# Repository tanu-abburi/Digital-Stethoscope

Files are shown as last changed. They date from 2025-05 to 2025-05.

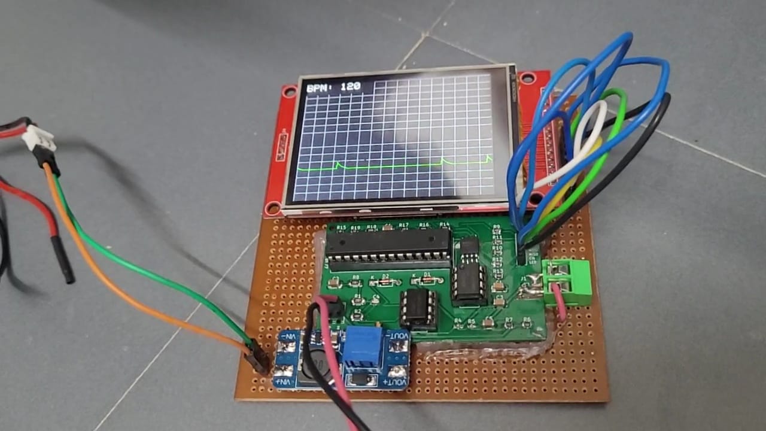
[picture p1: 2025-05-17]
Test setups/hr_120.jpeg

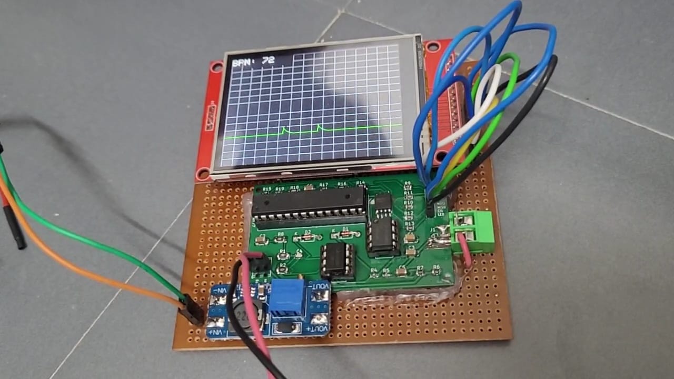
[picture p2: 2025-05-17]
Test setups/hr_72.jpeg

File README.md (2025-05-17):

# Digital Stethoscope  
A **digital stethoscope** that amplifies, filters, and digitally processes heart sounds for enhanced diagnostics and remote monitoring.  
## Project Outline
We intend on developing a digital stethoscope system which includes an acoustic sensor that is attached to the processing unit, which will catch the signal, amplify it using an amplifier circuit using an op amp TL082.
The amplified signal is then sent to the ATMEGA328-P, which then converts the analog signal to a digital one ,which is then displayed as a waveform on the LCD TFT screen.  We intend to 3D printing an enclosure which will offer mechanical support and keep the enclosure compact.
## Working
The custom acoustic sensor is positioned on a pulse point of the body.
The sound is transmitted to an amplifier circuit via a condenser microphone. 
The amplified signal is then sent to the A0 ADC pin of the  ATmega328P microcontroller, where it is processed and displayed on the LCD screen.
On the LCD screen, we display to waveform as well as the calculated BPM rate .

## Simulation Results
WhatsApp Image 2025-05-11 at 23 04 28

## Schematic

## PCB Layout and 3D view



##  Team Members  
- **Ashley Ann Benoy** - EE23BTECH11204  
- **Avani Chouhan** - EE23BTECH11205  
- **Abburi Tanusha** - EE23BTECH11201  
- **Manugunta Meghana Sai** - EE23BTECH11212  
- **Muthyala Nikhitha Sri** - EE23BTECH11213

## System

## References
https://circuitdigest.com/microcontroller-projects/diy-wireless-digital-stethoscope

https://people.ece.cornell.edu/land/courses/ece4760/FinalProjects/s2012/myw9_gdd9/myw9_gdd9/

https://circuitdigest.com/fullimage?i=circuitdiagram_mic/Wireless-Stethoscope-Circuit.png

https://www.youtube.com/watch?v=w6MbM_f_7Uo

https://www.youtube.com/watch?v=QSXJG3opua8&t=3s

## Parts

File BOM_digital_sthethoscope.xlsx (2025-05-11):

S.No | Components' name | Components' Value | Manufacturer name | Package/Footprint | Quantity | Cost per unit | Net cost | Brief Description
1 | Capacitors | 100 n | Robu | Smd 1206 | 10 | 1.54 | 15.4
2 |  | 10 u | Robu | smd 1206 | 20 | 9 | 180
3 |  | 500 p | Mouser Electronics | smd 0805 | 10 | 26 | 260
4 |  | 2.2u | Robu | smd 0805 | 10 | 5 | 50
5 |  | 470n | Robu | smd 1206 | 10 | 4 | 40
6 | Resistors | 10k | Robu | smd 0805 | 25 | 3 | 75
7 |  | 1k | Robu | smd 0805 | 20 | 0.65 | 13
8 |  | 20k | Robu | smd 0603 | 10 | 0.15 | 1.5
9 |  | 2.2k | Robu | smd 0805 | 10 | 0.98 | 9.8
10 |  | 1 Meg | Robu | smd 1206 | 10 | 0.65 | 6.5
11 |  | 100 | Robu | smd 0805 | 20 | 3 | 60
12 |  | 200 | Robu | smd 1206 | 15 | 0.49 | 7.35
13 |  | 3.3k | Robu | smd 1206 | 10 | 0.69 | 6.9
14 |  | 75 | Robu | smd 1206 | 10 | 1 | 10
15 |  | 100k | Robu | smd 1206 | 20 | 0.79 | 15.8
16 | Diode | Zener diode | Digikey | 1N4148: Diode_THT:D_DO-35_S0D27_P7.62MM_Horizontal | 10 | 8.63 | 86.3
17 | flash memory | W25Q80DVSSIG | robu | SOIC-8/SMD | 2 | 79 | 158 | Storing and transferring the data
18 | Stethoscope |  | ELKO |  | 2 | 1661 | 3322 | Detects heartbeats and transmits real-time pulse data for remote monitoring and analysis.
19 | microcontoller ic | ATmega328p | Robu | PDIP-28 | 2 | 340 | 680 | pulse width modulation and ADC unit
20 | voltage regulator |  | Robu | DIP | 3 | 101 | 303 | voltage regulator to output voltage of 3.3V
21 | 28 pin DIP IC Socket |  | Robu |  | 2 | 28 | 56 | Allows easy insertion and removal of 28-pin ICs
22 | Switch |  | Robu |  | 3 | 69 | 207 | Basic on/off switch with two terminals
23 | LCD screen | TFT 2.8 inch LCD screen touch enabled | robu |  | 2 | 746 | 1492 | For plotting the graph
24 | female header pin |  | robu |  | 1 | 127 | 127 | connecting header pins
25 | male header pin |  | robu |  | 1 | 100 | 100 | connecting header pins
26 | Operational amplifier | OA3 TL082 | Robu | DIP-8 | 4 | 132 | 528 | amplification of signal
27 | 1.2V Battery |  | Amazon |  | 2 | 954 | 1908 | Supply DC Power
28 | Microphone |  | MOUSER Electronics |  | 5 | 56 | 280 | Capturing input signal from stethoscope
29 | Battery Holder |  | Amazon |  | 2 | 149 | 298 | To hold the battery
30 | sd card |  | robu |  | 1 | 419 | 419 | additional memory
31 | DC-DC setup power module |  | robu |  | 2 | 36 | 72 | bb
32 | Lithium Battery |  | robu |  | 2 | 209 | 418 | power supply
33 | 9V Battery |  | Amazon |  | 1 | 249 | 249 | Supply DC Power
34 | Terminal Block |  | robu |  | 2 | 8 | 16

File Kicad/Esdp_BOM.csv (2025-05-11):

Reference | Value | Datasheet | Footprint | Qty | DNP
C1,C3 | 100nF | ~ | Capacitor_SMD:C_1206_3216Metric | 2
C2,C5,C6 | 10uF | ~ | Capacitor_SMD:C_1206_3216Metric | 3
C4 | 500pF | ~ | Capacitor_SMD:C_0805_2012Metric | 1
D1,D2 | 1N4148 | https://assets.nexperia.com/documents/data-sheet/1N4148_1N4448.pdf | Diode_THT:D_DO-35_SOD27_P7.62mm_Horizontal | 2
IC1 | W25Q80DVSSIG |  | W25Q80DVSSIG:SOIC8-FLASH | 1
J1 | Conn_01x02_Pin | ~ | Connector_PinSocket_1.27mm:PinSocket_1x02_P1.27mm_Vertical | 1
J2 | Screw_Terminal_01x02 | ~ | TerminalBlock_Phoenix:TerminalBlock_Phoenix_MPT-0,5-2-2.54_1x02_P2.54mm_Horizontal | 1
J3 | Conn_01x09_Pin | ~ | Connector_PinSocket_1.27mm:PinSocket_1x09_P1.27mm_Vertical | 1
R1,R8 | 3.3k | ~ | Resistor_SMD:R_1206_3216Metric | 2
R2 | 1M | ~ | Resistor_SMD:R_1206_3216Metric | 1
R3,R9,R10,R11,R12,R13 | 10k | ~ | Resistor_SMD:R_0805_2012Metric | 6
R4,R5 | 20k | ~ | Resistor_SMD:R_0603_1608Metric | 2
R6,R7 | 1k | ~ | Resistor_SMD:R_0805_2012Metric | 2
R14,R16,R18 | 200 | ~ | Resistor_SMD:R_1206_3216Metric | 3
R15,R17,R19 | 100 | ~ | Resistor_SMD:R_0805_2012Metric | 3
U1 | ATmega328-P | http://ww1.microchip.com/downloads/en/DeviceDoc/ATmega328_P%20AVR%20MCU%20with%20picoPower%20Technology%20Data%20Sheet%2040001984A.pdf | Package_DIP:DIP-28_W7.62mm_Socket | 1
U2 | TL082 | http://www.ti.com/lit/ds/symlink/tl081.pdf | Package_DIP:DIP-8_W7.62mm_LongPads | 1
U3 | LP2951-3.3_DIP | http://www.ti.com/lit/ds/symlink/lp2951.pdf | Package_DIP:DIP-8_W7.62mm | 1

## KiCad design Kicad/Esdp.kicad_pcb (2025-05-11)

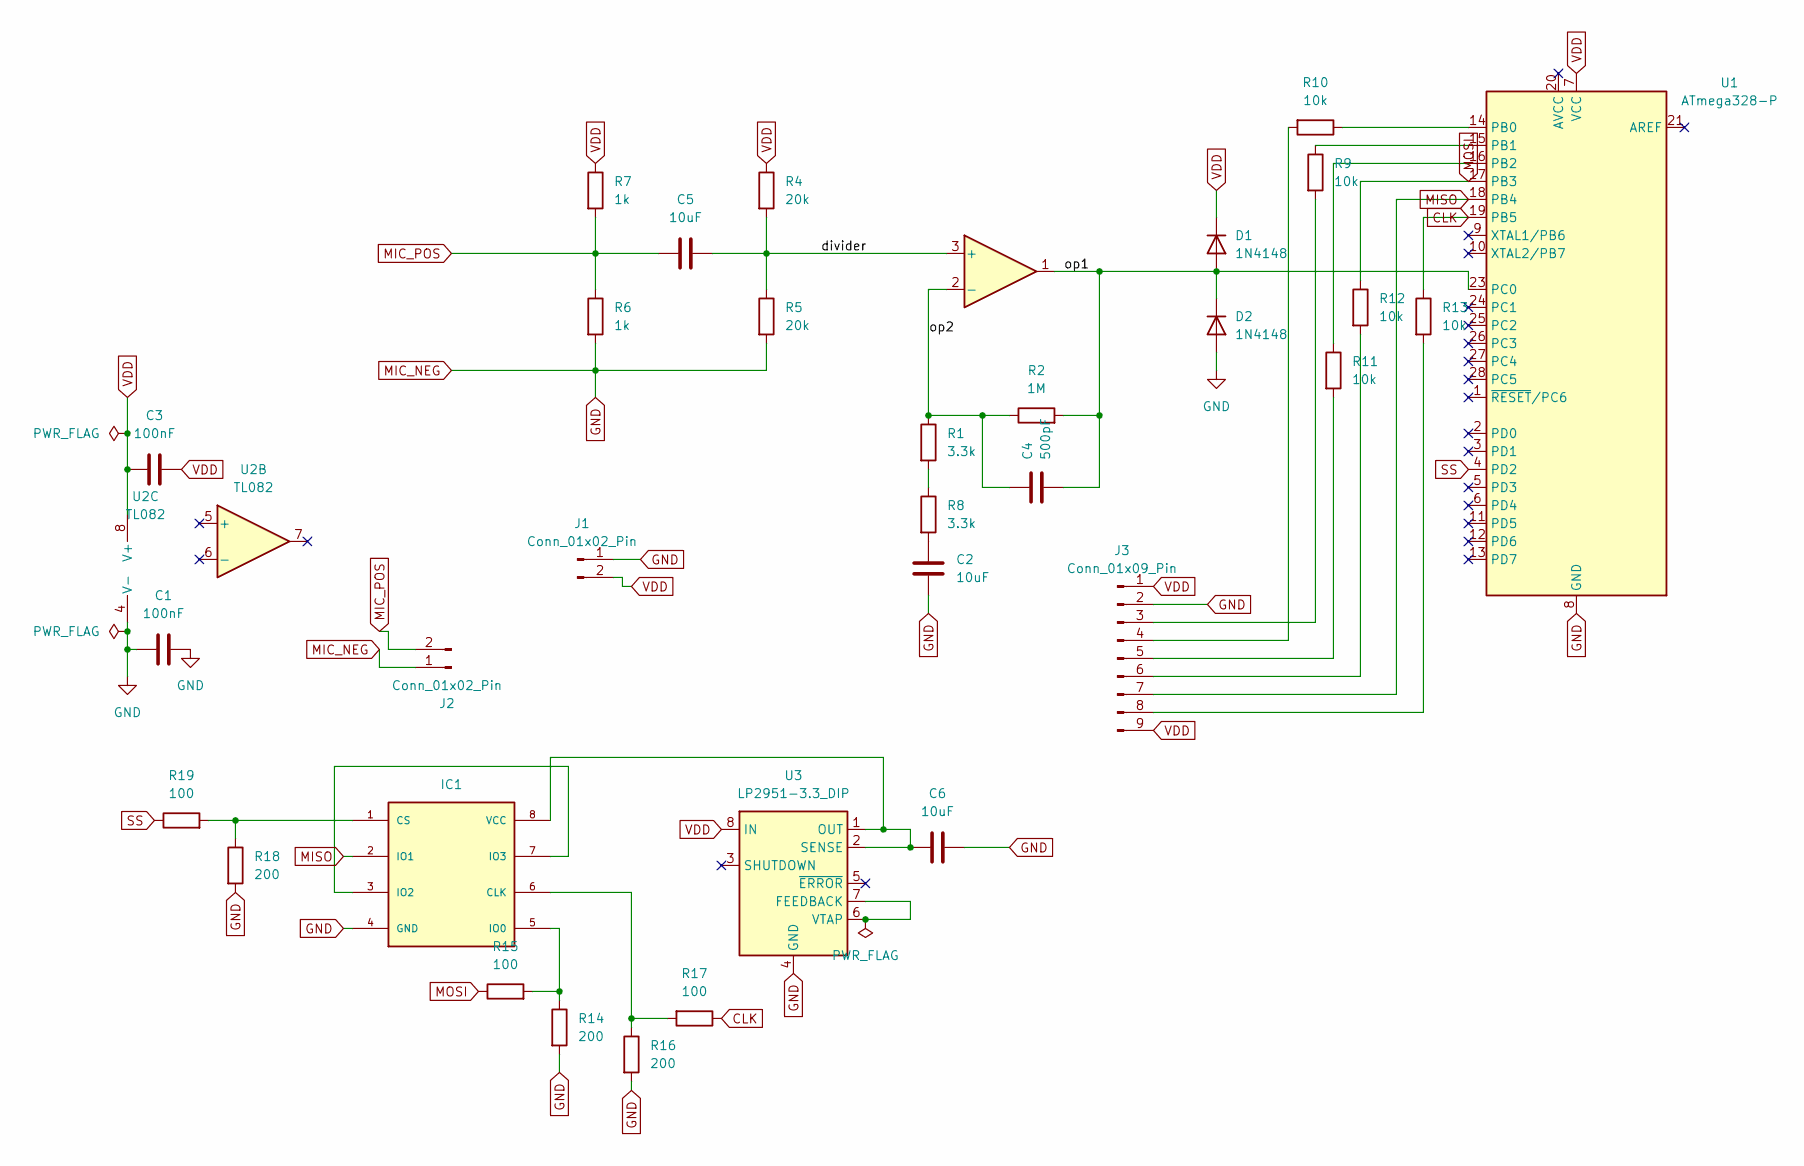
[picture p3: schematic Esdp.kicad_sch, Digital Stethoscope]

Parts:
C1, C3: 100nF; C_1206_3216Metric
C2, C5, C6: 10uF; C_1206_3216Metric
C4: 500pF; C_0805_2012Metric
D1, D2: 1N4148; D_DO-35_SOD27_P7.62mm_Horizontal
IC1: W25Q80DVSSIG; SOIC8-FLASH
J1: Conn_01x02_Pin; PinSocket_1x02_P1.27mm_Vertical
J2: Conn_01x02_Pin; TerminalBlock_Phoenix_MPT-0,5-2-2.54_1x02_P2.54mm_Horizontal
J3: Conn_01x09_Pin; PinSocket_1x09_P1.27mm_Vertical
R1, R8: 3.3k; R_1206_3216Metric
R2: 1M; R_1206_3216Metric
R4, R5: 20k; R_0603_1608Metric
R6, R7: 1k; R_0805_2012Metric
R9, R10, R11, R12, R13: 10k; R_0805_2012Metric
R14, R16, R18: 200; R_1206_3216Metric
R15, R17, R19: 100; R_0805_2012Metric
U1: ATmega328-P; DIP-28_W7.62mm_Socket
U2: TL082; DIP-8_W7.62mm_LongPads
U3: LP2951-3.3_DIP; DIP-8_W7.62mm

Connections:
/divider: C5.1, R4.2, R5.1, U2.3 (+)
/op1: C4.2, D1.2 (A), D2.1 (K), R2.2, U1.23 (PC0), U2.1
/op2: C4.1, R1.1, R2.1, U2.2 (-)
CLK: R13.1, R17.1, U1.19 (PB5)
GND: C1.1, C1.2, C2.2, C6.1, D2.2 (A), IC1.4 (GND), J1.1, J2.1, J3.2, R5.2, R6.2, R14.2, R16.2, R18.2, U1.8 (GND), U1.22 (GND), U2.4 (V-), U3.4 (GND)
MIC_POS: C5.2, J2.2, R6.1, R7.2
MISO: IC1.2 (IO1), J3.7, U1.18 (PB4)
MOSI: R12.1, R15.1, U1.17 (PB3)
unnamed: C2.1, R8.2
unnamed: IC1.6 (CLK), R16.1, R17.2
unnamed: IC1.1 (CS), R18.1, R19.2
unnamed: IC1.5 (IO0), R14.1, R15.2
unnamed: IC1.3 (IO2), IC1.7 (IO3)
unnamed: C6.2, IC1.8 (VCC), U3.1 (OUT), U3.2 (SENSE)
unnamed: J3.3, R9.2
unnamed: J3.4, R10.2
unnamed: J3.5, R11.2
unnamed: J3.6, R12.2
unnamed: J3.8, R13.2
unnamed: R1.2, R8.1
unnamed: R10.1, U1.14 (PB0)
unnamed: R9.1, U1.15 (PB1)
unnamed: R11.1, U1.16 (PB2)
unnamed: U3.6 (VTAP), U3.7 (FEEDBACK)
SS: R19.1, U1.4 (PD2)
VDD: C3.1, C3.2, D1.1 (K), J1.2, J3.1, J3.9, R4.1, R7.1, U1.7 (VCC), U2.8 (V+), U3.8 (IN)

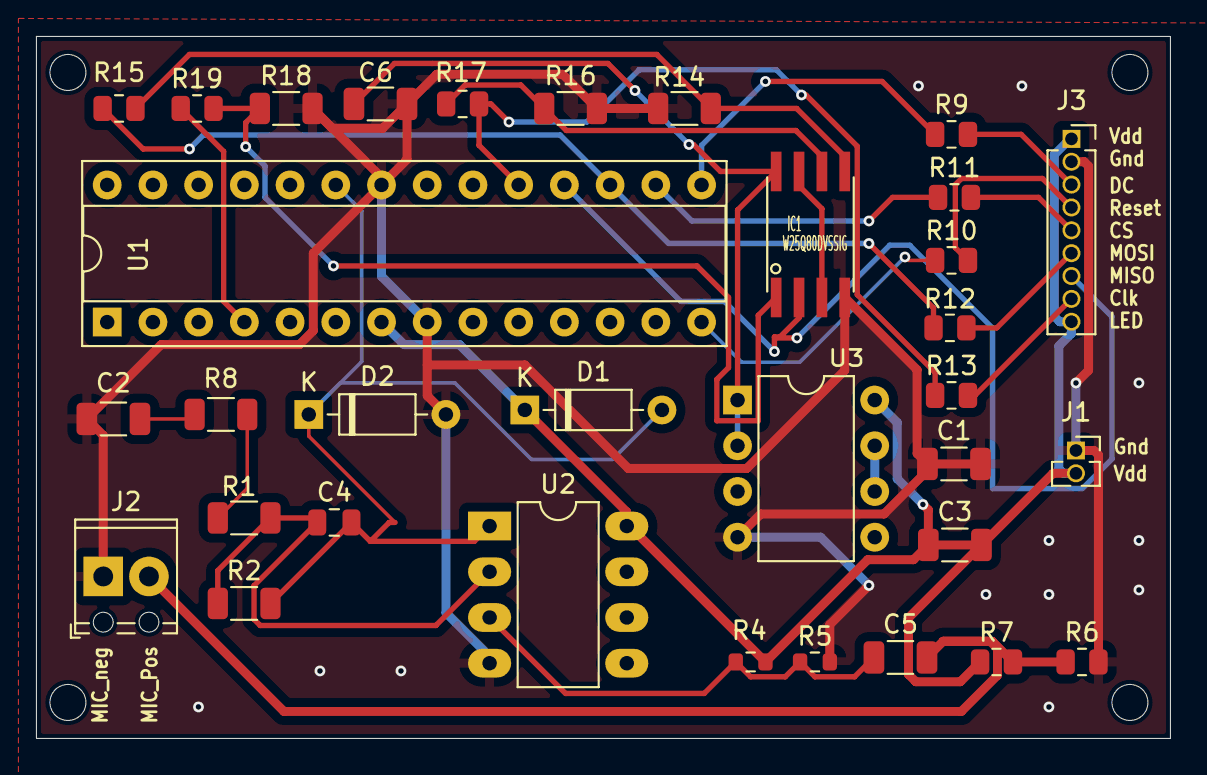
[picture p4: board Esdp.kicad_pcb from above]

Board: 2 copper layers, 63.0 x 39.0 mm, 33 parts (0 on the bottom side), 26 nets.
